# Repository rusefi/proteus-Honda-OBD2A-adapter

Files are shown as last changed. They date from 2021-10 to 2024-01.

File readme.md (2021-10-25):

https://github.com/rusefi/rusefi and https://github.com/mck1117/proteus

https://github.com/rusefi/rusefi/wiki/Vault-Of-Honda-OEM#obd-2

https://github.com/rusefi/rusefi/wiki/Honda-Civic-1996

[Connector spreadsheet](https://docs.google.com/spreadsheets/d/1NOu2Atvwz7war0sTAcp2MZZhsYdLY6VmwkuC-S1-yEU)

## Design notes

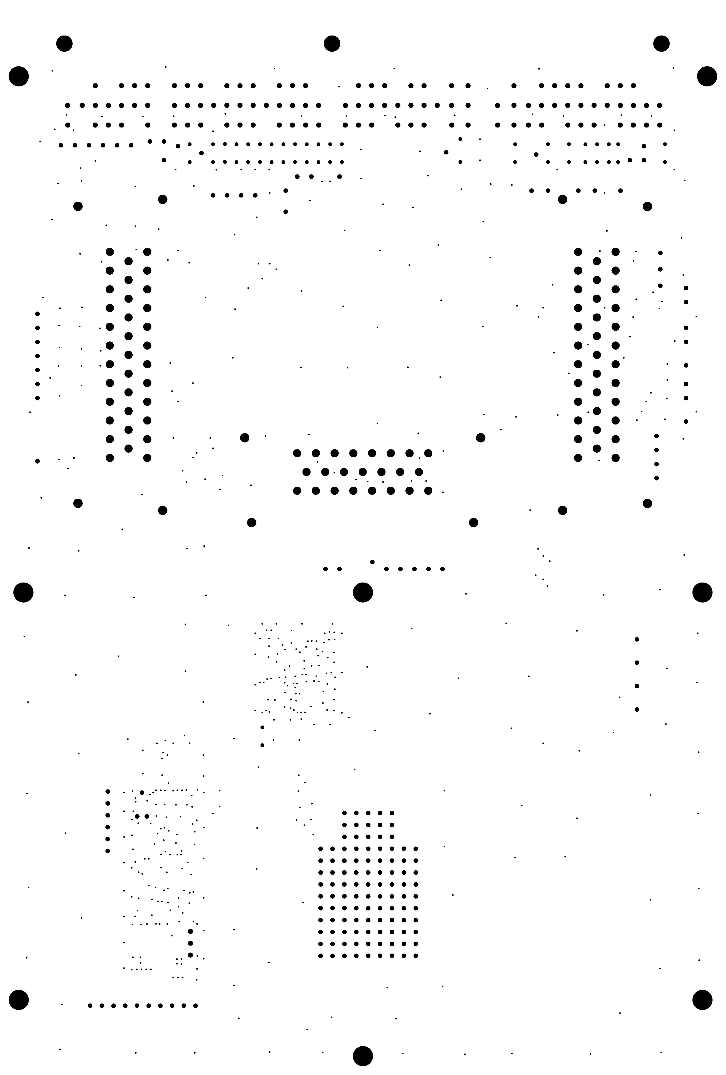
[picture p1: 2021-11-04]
boards/proteusOBD2Ahonda-a/boards/proteusOBD2Ahonda-a/board/misc/proteusOBD2Ahonda-a-outline.png

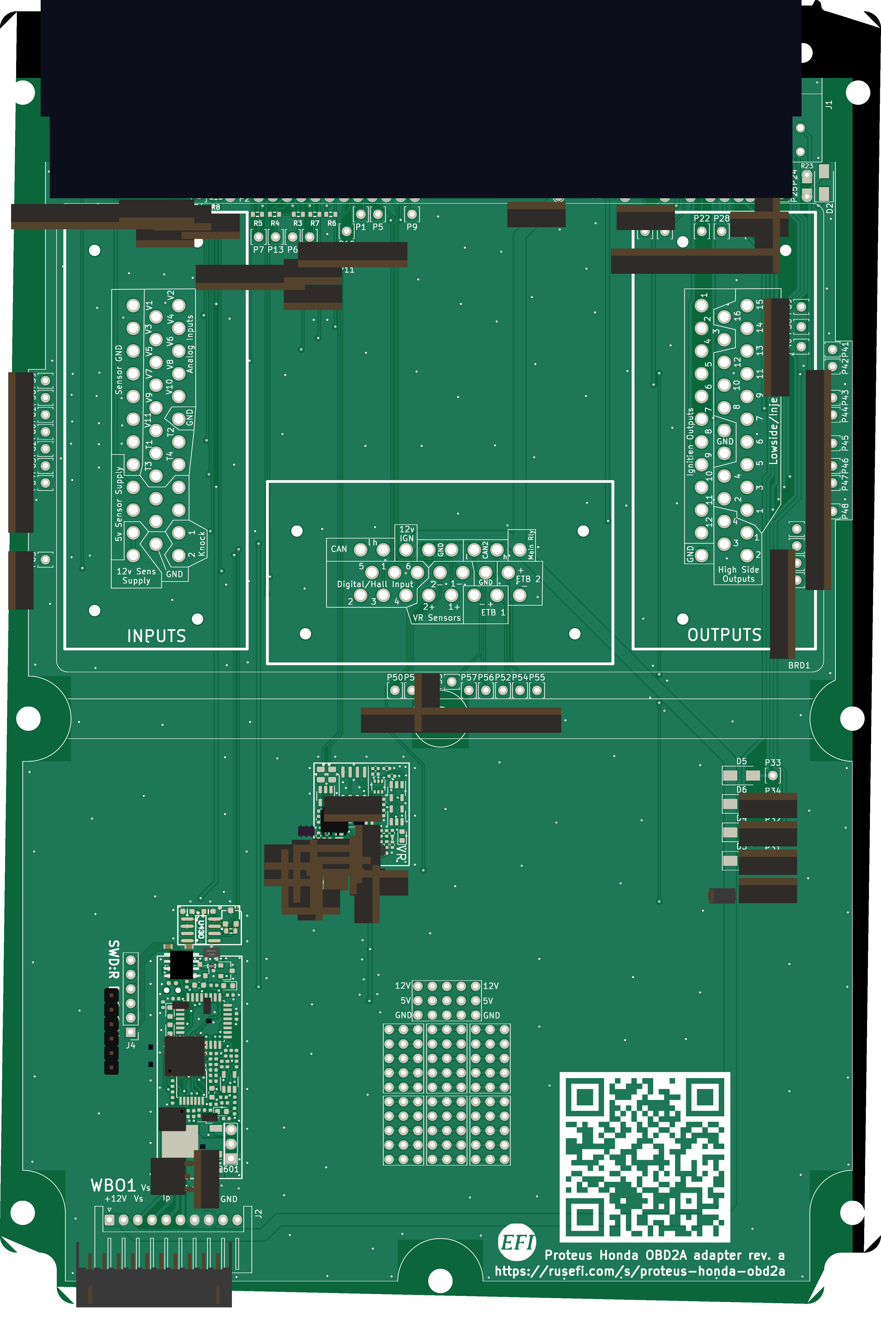
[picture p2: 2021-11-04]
boards/proteusOBD2Ahonda-a/boards/proteusOBD2Ahonda-a/board/proteusOBD2Ahonda-a.png

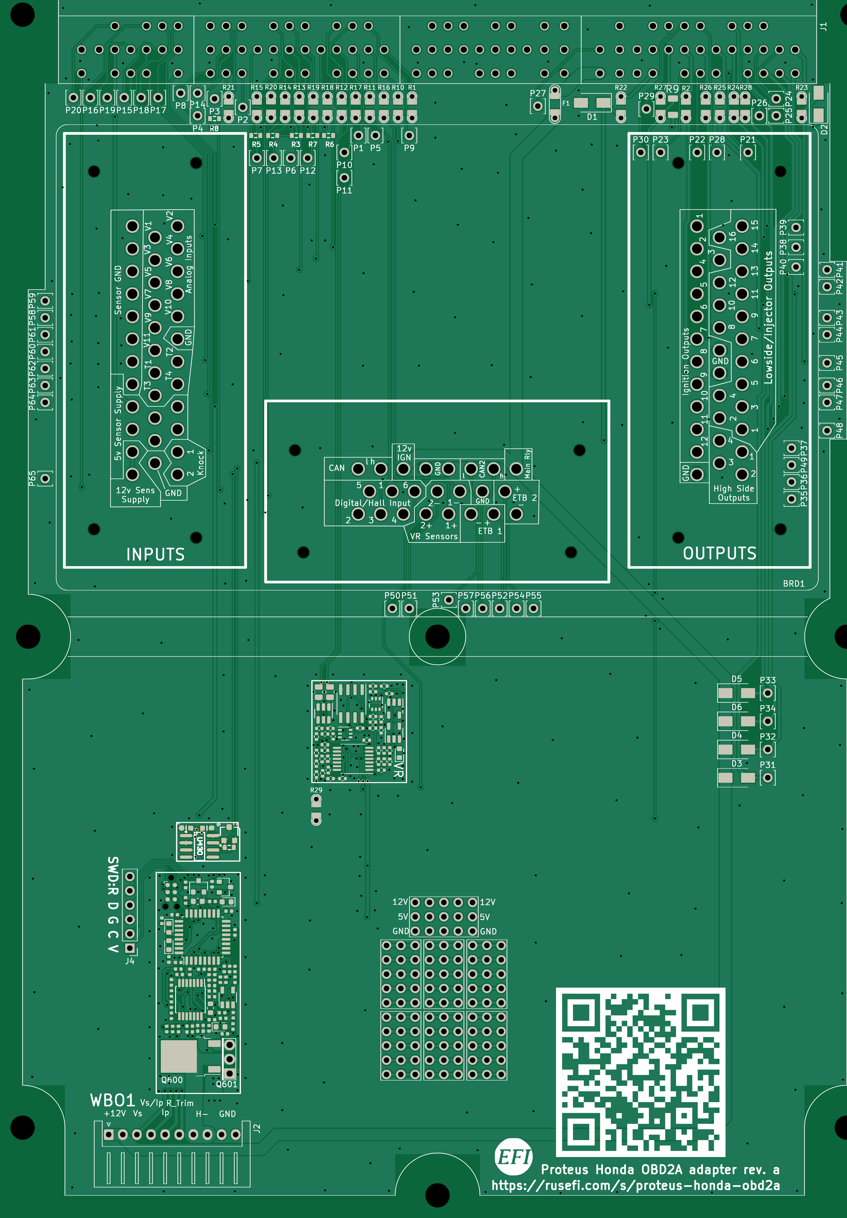
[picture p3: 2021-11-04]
boards/proteusOBD2Ahonda-a/boards/proteusOBD2Ahonda-a/board/misc/proteusOBD2Ahonda-a-top.png

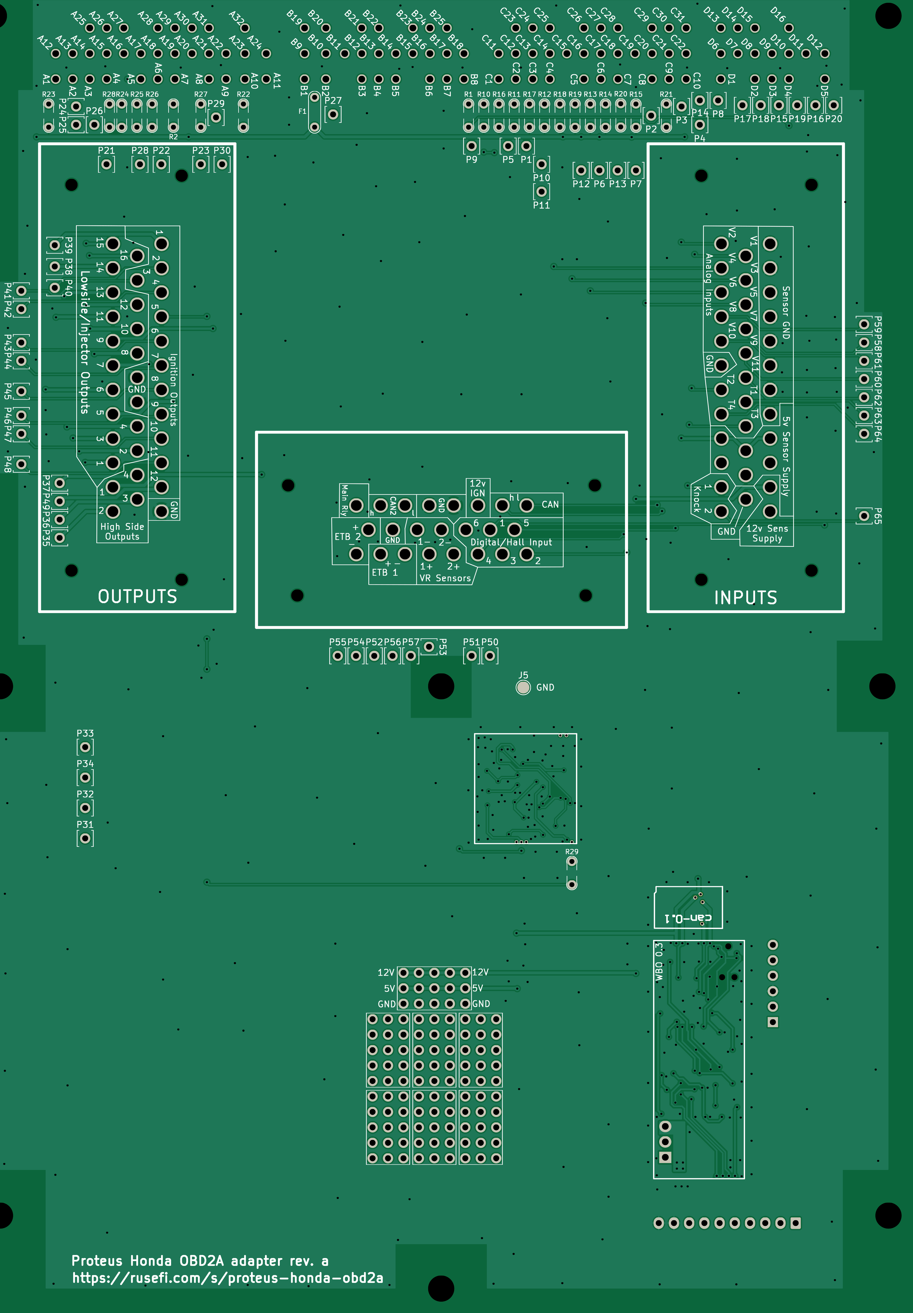
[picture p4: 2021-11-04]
boards/proteusOBD2Ahonda-a/boards/proteusOBD2Ahonda-a/board/misc/proteusOBD2Ahonda-a-bottom.png

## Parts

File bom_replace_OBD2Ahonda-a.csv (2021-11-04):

#WBO low-side (D2PAK | TO220)
Q600
Q601
#WBO STM32
U602

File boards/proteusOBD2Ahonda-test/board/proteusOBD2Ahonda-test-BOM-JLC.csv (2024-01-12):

Comment | Designator | Footprint | LCSC Part #
SS34 | D1, D2, D3, D4, D5, D6 | D_SMA | C8678
Fuse-Pad-Pad | F1 | PAD-1206-PAD | C182446
XH-10AW | J2 | JST_XH_S10B-XH-A_1x10_P2.50mm_Horizontal | C14652
Jumper-Pad-Pad | R1, R2, R10, R11, R12, R13, R14, R15, R16, R17, R18, R19, R20, R21, R22, R23, R24, R25, R26, R27, R28, R29 | PAD-0805-PAD | C17477
4.7k | R3, R4, R5, R6, R7, R8 | R0603 | C23162
1k | R9 | R1206 | C4410
1n | C751 | C0402 | C1523
470n | C752 | C0402 | C47339
100n | C753, C754, C759, C601, C602, C605, C608, C612, C613, C614, C615 | C0402 | C1525
1u | C755, C758, C761, C762, C763, C765, C766, C767, C600, C607, C609, C610, C611 | C0402 | C52923
10n | C756, C757, C760, C764 | C0402 | C15195
LED-GREEN-0603 | D751, D601 | LED-0603 | C72043
2.2k | R751 | R0402 | C25879
10k | R752, R753 | R0805 | C17414
12k | R754 | R0402 | C25752
100k | R755, R756, R758, R759, R615, R621 | R0402 | C25741
10k | R757, R762, R763, R767, R768, R604, R605, R613, R614, R618, R619, R625 | R0402 | C25744
68k | R760, R602, R603 | R0402 | C36871
10 | R761, R764, R769, R606 | R0402 | C25077
1k | R765, R766, R600, R601, R616, R617, R622, R626, R627, R628 | R0402 | C11702
SRV05-4-P-T7 | U751 | SOT23-6 | C85364
74AHC1G02 | U752, U757 | SOT23-5 | C7463
MCP6004 | U753, U600 | TSSOP14 | C50282
MAX9142 | U754 | SO8 | C18567
NC7SB3157P6X | U755, U756 | SOT-363 | C87403
33n | C603 | C0402 | C1585
4.7u | C616 | C0603 | C19666
LED-RED-0603 | D600, D603 | LED-0603 | C2286
LED-BLUE-0603 | D602 | LED-0603 | C72041
22k | R607 | R0402 | C25768
47 | R608 | R0402 | C25118
61.9 | R609 | R0603 | C23092
20k | R610, R611, R612 | R0402 | C25765
27k | R620, R623 | R0402 | C25771
3.3k | R624 | R0402 | C25890
AD8628 | U601 | TSOT23-5 | C29309
REF3033 | U603 | SOT-23 | C36658
XC6206P332MR | U604 | SOT-23 | C5446
100n | C430, C431 | C0603 | C14663
PESD1CAN | D430 | SOT-23 | C343993
120 | R430 | R0603 | C22787
TJA1051T/3/1J | U430 | SO8 | C38695

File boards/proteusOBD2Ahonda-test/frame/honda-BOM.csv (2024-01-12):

Comment | Designator | Footprint | LCSC Part #
proteus | BRD1 | proteus
SS34 | D1 | D_SMA | C8678
SS34 | D2 | D_SMA | C8678
SS34 | D3 | D_SMA | C8678
SS34 | D4 | D_SMA | C8678
SS34 | D5 | D_SMA | C8678
SS34 | D6 | D_SMA | C8678
Fuse-Pad-Pad | F1 | PAD-1206-PAD | C182446
RUSEFI_LOGO | G1 | rusefi_logo
PROTO_AREA | G2 | PROTO_AREA
PROTO_AREA | G3 | PROTO_AREA
PROTO_AREA | G4 | PROTO_AREA
PROTO_AREA | G5 | PROTO_AREA
PROTO_AREA | G6 | PROTO_AREA
PROTO_AREA | G7 | PROTO_AREA
PROTO_AREA | G8 | PROTO_AREA
MountingHole | H1 | MountingHole_4.3mm_M4
MountingHole | H2 | MountingHole_4.3mm_M4
MountingHole | H3 | MountingHole_4.3mm_M4
MountingHole | H4 | MountingHole_4.3mm_M4
MountingHole | H5 | MountingHole_4.3mm_M4
MountingHole | H6 | MountingHole_4.3mm_M4
MountingHole | H7 | MountingHole_4.3mm_M4
MountingHole | H8 | MountingHole_4.3mm_M4
TE_179686-6_104pin_Connector | J1 | TE_179686-6_104pin_Connector
XH-10AW | J2 | JST_XH_S10B-XH-A_1x10_P2.50mm_Horizontal | C14652
XH-10A | J3 | JST_XH_B10B-XH-A_1x10_P2.50mm_Vertical
Conn_01x06 | J4 | PinHeader_1x06_P2.54mm_Vertical
Conn_01x01 | J5 | TestPoint_Pad_D2.0mm
Module:vr-discrete/0.1 | M1 | vr-discrete
Module:wbo/0.3 | M2 | wbo
Module:can/0.1 | M3 | can
Pad | P1 | PAD-TH
Pad | P2 | PAD-TH
Pad | P3 | PAD-TH
Pad | P4 | PAD-TH
Pad | P5 | PAD-TH
Pad | P6 | PAD-TH
Pad | P7 | PAD-TH
Pad | P8 | PAD-TH
Pad | P9 | PAD-TH
Pad | P10 | PAD-TH
Pad | P11 | PAD-TH
Pad | P12 | PAD-TH
Pad | P13 | PAD-TH
Pad | P14 | PAD-TH
Pad | P15 | PAD-TH
Pad | P16 | PAD-TH
Pad | P17 | PAD-TH
Pad | P18 | PAD-TH
Pad | P19 | PAD-TH
Pad | P20 | PAD-TH
Pad | P21 | PAD-TH
Pad | P22 | PAD-TH
Pad | P23 | PAD-TH
Pad | P24 | PAD-TH
Pad | P25 | PAD-TH
Pad | P26 | PAD-TH
Pad | P27 | PAD-TH
Pad | P28 | PAD-TH
Pad | P29 | PAD-TH
Pad | P30 | PAD-TH
Pad | P31 | PAD-TH
Pad | P32 | PAD-TH
Pad | P33 | PAD-TH
Pad | P34 | PAD-TH
Pad | P35 | PAD-TH
Pad | P36 | PAD-TH
Pad | P37 | PAD-TH
Pad | P38 | PAD-TH
Pad | P39 | PAD-TH
Pad | P40 | PAD-TH
Pad | P41 | PAD-TH
Pad | P42 | PAD-TH
Pad | P43 | PAD-TH
Pad | P44 | PAD-TH
Pad | P45 | PAD-TH
Pad | P46 | PAD-TH
Pad | P47 | PAD-TH
Pad | P48 | PAD-TH
Pad | P49 | PAD-TH
Pad | P50 | PAD-TH
Pad | P51 | PAD-TH
Pad | P52 | PAD-TH
Pad | P53 | PAD-TH
Pad | P54 | PAD-TH
Pad | P55 | PAD-TH
Pad | P56 | PAD-TH
Pad | P57 | PAD-TH
Pad | P58 | PAD-TH
Pad | P59 | PAD-TH
Pad | P60 | PAD-TH
Pad | P61 | PAD-TH
Pad | P62 | PAD-TH
Pad | P63 | PAD-TH
Pad | P64 | PAD-TH
Pad | P65 | PAD-TH
Jumper-Pad-Pad | R1 | PAD-0805-PAD | C17477
Jumper-Pad-Pad | R2 | PAD-0805-PAD | C17477
4.7k | R3 | R0603 | C23162
4.7k | R4 | R0603 | C23162
4.7k | R5 | R0603 | C23162
4.7k | R6 | R0603 | C23162
4.7k | R7 | R0603 | C23162
4.7k | R8 | R0603 | C23162
1k | R9 | R1206 | C4410
Jumper-Pad-Pad | R10 | PAD-0805-PAD | C17477
Jumper-Pad-Pad | R11 | PAD-0805-PAD | C17477
Jumper-Pad-Pad | R12 | PAD-0805-PAD | C17477
Jumper-Pad-Pad | R13 | PAD-0805-PAD | C17477
Jumper-Pad-Pad | R14 | PAD-0805-PAD | C17477
Jumper-Pad-Pad | R15 | PAD-0805-PAD | C17477
Jumper-Pad-Pad | R16 | PAD-0805-PAD | C17477
Jumper-Pad-Pad | R17 | PAD-0805-PAD | C17477
Jumper-Pad-Pad | R18 | PAD-0805-PAD | C17477
Jumper-Pad-Pad | R19 | PAD-0805-PAD | C17477
Jumper-Pad-Pad | R20 | PAD-0805-PAD | C17477
Jumper-Pad-Pad | R21 | PAD-0805-PAD | C17477
Jumper-Pad-Pad | R22 | PAD-0805-PAD | C17477
Jumper-Pad-Pad | R23 | PAD-0805-PAD | C17477
Jumper-Pad-Pad | R24 | PAD-0805-PAD | C17477
Jumper-Pad-Pad | R25 | PAD-0805-PAD | C17477
Jumper-Pad-Pad | R26 | PAD-0805-PAD | C17477
Jumper-Pad-Pad | R27 | PAD-0805-PAD | C17477
Jumper-Pad-Pad | R28 | PAD-0805-PAD | C17477
Jumper-Pad-Pad | R29 | PAD-0805-PAD | C17477

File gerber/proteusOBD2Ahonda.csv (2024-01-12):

Comment | Designator | Footprint | LCSC Part #
proteus | BRD1 | kicad6-libraries:proteus
SS34 | D1 | Diode_SMD:D_SMA | C8678
SS34 | D2 | Diode_SMD:D_SMA | C8678
SS34 | D3 | Diode_SMD:D_SMA | C8678
SS34 | D4 | Diode_SMD:D_SMA | C8678
SS34 | D5 | Diode_SMD:D_SMA | C8678
SS34 | D6 | Diode_SMD:D_SMA | C8678
Fuse-Pad-Pad | F1 | hellen-one-common:PAD-1206-PAD | C182446
RUSEFI_LOGO | G1 | kicad6-libraries:rusefi_logo
PROTO_AREA | G2 | hellen-one-common:PROTO_AREA
PROTO_AREA | G3 | hellen-one-common:PROTO_AREA
PROTO_AREA | G4 | hellen-one-common:PROTO_AREA
PROTO_AREA | G5 | hellen-one-common:PROTO_AREA
PROTO_AREA | G6 | hellen-one-common:PROTO_AREA
PROTO_AREA | G7 | hellen-one-common:PROTO_AREA
PROTO_AREA | G8 | hellen-one-common:PROTO_AREA
MountingHole | H1 | MountingHole:MountingHole_4.3mm_M4
MountingHole | H2 | MountingHole:MountingHole_4.3mm_M4
MountingHole | H3 | MountingHole:MountingHole_4.3mm_M4
MountingHole | H4 | MountingHole:MountingHole_4.3mm_M4
MountingHole | H5 | MountingHole:MountingHole_4.3mm_M4
MountingHole | H6 | MountingHole:MountingHole_4.3mm_M4
MountingHole | H7 | MountingHole:MountingHole_4.3mm_M4
MountingHole | H8 | MountingHole:MountingHole_4.3mm_M4
TE_179686-6_104pin_Connector | J1 | kicad6-libraries:TE_179686-6_104pin_Connector
XH-10AW | J2 | Connector_JST:JST_XH_S10B-XH-A_1x10_P2.50mm_Horizontal | C14652
XH-10A | J3 | Connector_JST:JST_XH_B10B-XH-A_1x10_P2.50mm_Vertical
Conn_01x06 | J4 | Connector_PinHeader_2.54mm:PinHeader_1x06_P2.54mm_Vertical
Conn_01x01 | J5 | TestPoint:TestPoint_Pad_D2.0mm
Module-vr-discrete-0.1 | M1 | hellen-one-vr-discrete-0.1:vr-discrete
Module-wbo-0.3 | M2 | hellen-one-wbo-0.3:wbo
Module-can-0.1 | M3 | hellen-one-can-0.1:can
Pad | P1 | hellen-one-common:PAD-TH
Pad | P2 | hellen-one-common:PAD-TH
Pad | P3 | hellen-one-common:PAD-TH
Pad | P4 | hellen-one-common:PAD-TH
Pad | P5 | hellen-one-common:PAD-TH
Pad | P6 | hellen-one-common:PAD-TH
Pad | P7 | hellen-one-common:PAD-TH
Pad | P8 | hellen-one-common:PAD-TH
Pad | P9 | hellen-one-common:PAD-TH
Pad | P10 | hellen-one-common:PAD-TH
Pad | P11 | hellen-one-common:PAD-TH
Pad | P12 | hellen-one-common:PAD-TH
Pad | P13 | hellen-one-common:PAD-TH
Pad | P14 | hellen-one-common:PAD-TH
Pad | P15 | hellen-one-common:PAD-TH
Pad | P16 | hellen-one-common:PAD-TH
Pad | P17 | hellen-one-common:PAD-TH
Pad | P18 | hellen-one-common:PAD-TH
Pad | P19 | hellen-one-common:PAD-TH
Pad | P20 | hellen-one-common:PAD-TH
Pad | P21 | hellen-one-common:PAD-TH
Pad | P22 | hellen-one-common:PAD-TH
Pad | P23 | hellen-one-common:PAD-TH
Pad | P24 | hellen-one-common:PAD-TH
Pad | P25 | hellen-one-common:PAD-TH
Pad | P26 | hellen-one-common:PAD-TH
Pad | P27 | hellen-one-common:PAD-TH
Pad | P28 | hellen-one-common:PAD-TH
Pad | P29 | hellen-one-common:PAD-TH
Pad | P30 | hellen-one-common:PAD-TH
Pad | P31 | hellen-one-common:PAD-TH
Pad | P32 | hellen-one-common:PAD-TH
Pad | P33 | hellen-one-common:PAD-TH
Pad | P34 | hellen-one-common:PAD-TH
Pad | P35 | hellen-one-common:PAD-TH
Pad | P36 | hellen-one-common:PAD-TH
Pad | P37 | hellen-one-common:PAD-TH
Pad | P38 | hellen-one-common:PAD-TH
Pad | P39 | hellen-one-common:PAD-TH
Pad | P40 | hellen-one-common:PAD-TH
Pad | P41 | hellen-one-common:PAD-TH
Pad | P42 | hellen-one-common:PAD-TH
Pad | P43 | hellen-one-common:PAD-TH
Pad | P44 | hellen-one-common:PAD-TH
Pad | P45 | hellen-one-common:PAD-TH
Pad | P46 | hellen-one-common:PAD-TH
Pad | P47 | hellen-one-common:PAD-TH
Pad | P48 | hellen-one-common:PAD-TH
Pad | P49 | hellen-one-common:PAD-TH
Pad | P50 | hellen-one-common:PAD-TH
Pad | P51 | hellen-one-common:PAD-TH
Pad | P52 | hellen-one-common:PAD-TH
Pad | P53 | hellen-one-common:PAD-TH
Pad | P54 | hellen-one-common:PAD-TH
Pad | P55 | hellen-one-common:PAD-TH
Pad | P56 | hellen-one-common:PAD-TH
Pad | P57 | hellen-one-common:PAD-TH
Pad | P58 | hellen-one-common:PAD-TH
Pad | P59 | hellen-one-common:PAD-TH
Pad | P60 | hellen-one-common:PAD-TH
Pad | P61 | hellen-one-common:PAD-TH
Pad | P62 | hellen-one-common:PAD-TH
Pad | P63 | hellen-one-common:PAD-TH
Pad | P64 | hellen-one-common:PAD-TH
Pad | P65 | hellen-one-common:PAD-TH
Jumper-Pad-Pad | R1 | hellen-one-common:PAD-0805-PAD | C17477
Jumper-Pad-Pad | R2 | hellen-one-common:PAD-0805-PAD | C17477
4.7k | R3 | hellen-one-common:R0603 | C23162
4.7k | R4 | hellen-one-common:R0603 | C23162
4.7k | R5 | hellen-one-common:R0603 | C23162
4.7k | R6 | hellen-one-common:R0603 | C23162
4.7k | R7 | hellen-one-common:R0603 | C23162
4.7k | R8 | hellen-one-common:R0603 | C23162
1k | R9 | hellen-one-common:R1206 | C4410
Jumper-Pad-Pad | R10 | hellen-one-common:PAD-0805-PAD | C17477
Jumper-Pad-Pad | R11 | hellen-one-common:PAD-0805-PAD | C17477
Jumper-Pad-Pad | R12 | hellen-one-common:PAD-0805-PAD | C17477
Jumper-Pad-Pad | R13 | hellen-one-common:PAD-0805-PAD | C17477
Jumper-Pad-Pad | R14 | hellen-one-common:PAD-0805-PAD | C17477
Jumper-Pad-Pad | R15 | hellen-one-common:PAD-0805-PAD | C17477
Jumper-Pad-Pad | R16 | hellen-one-common:PAD-0805-PAD | C17477
Jumper-Pad-Pad | R17 | hellen-one-common:PAD-0805-PAD | C17477
Jumper-Pad-Pad | R18 | hellen-one-common:PAD-0805-PAD | C17477
Jumper-Pad-Pad | R19 | hellen-one-common:PAD-0805-PAD | C17477
Jumper-Pad-Pad | R20 | hellen-one-common:PAD-0805-PAD | C17477
Jumper-Pad-Pad | R21 | hellen-one-common:PAD-0805-PAD | C17477
Jumper-Pad-Pad | R22 | hellen-one-common:PAD-0805-PAD | C17477
Jumper-Pad-Pad | R23 | hellen-one-common:PAD-0805-PAD | C17477
Jumper-Pad-Pad | R24 | hellen-one-common:PAD-0805-PAD | C17477
Jumper-Pad-Pad | R25 | hellen-one-common:PAD-0805-PAD | C17477
Jumper-Pad-Pad | R26 | hellen-one-common:PAD-0805-PAD | C17477
Jumper-Pad-Pad | R27 | hellen-one-common:PAD-0805-PAD | C17477
Jumper-Pad-Pad | R28 | hellen-one-common:PAD-0805-PAD | C17477
Jumper-Pad-Pad | R29 | hellen-one-common:PAD-0805-PAD | C17477

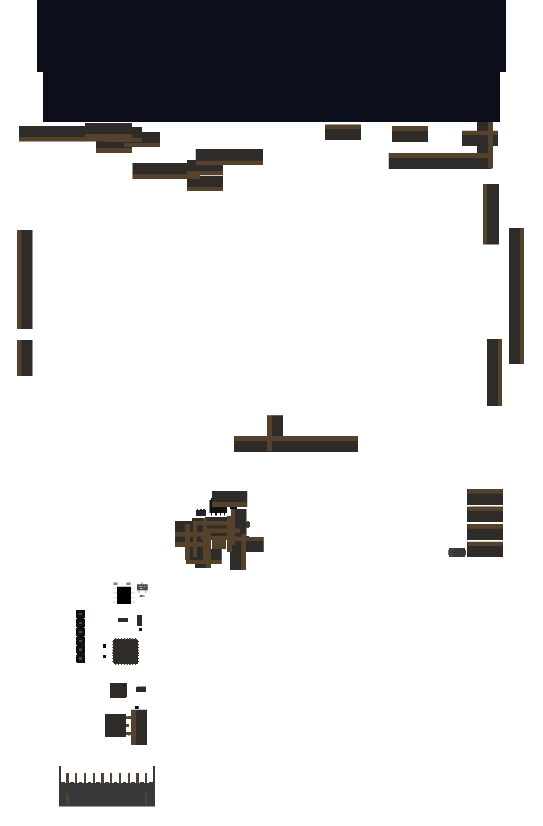
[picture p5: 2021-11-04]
boards/proteusOBD2Ahonda-a/boards/proteusOBD2Ahonda-a/board/misc/proteusOBD2Ahonda-a-components.png

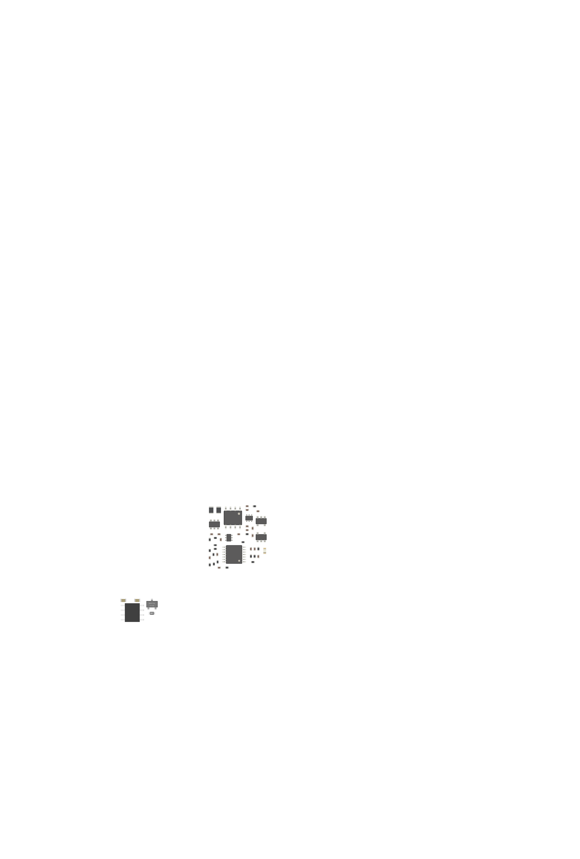
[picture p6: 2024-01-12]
boards/proteusOBD2Ahonda-test/board/misc/proteusOBD2Ahonda-test-components.png

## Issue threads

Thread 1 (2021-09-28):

Data readiness

rusefillc, 2021-09-28:
https://www.ek9.org/index.php?threads/honda-usefull-ecu-pinouts-obd2b-obd2a-obd1.201/

rusefillc, 2021-09-28:
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

rusefillc, 2021-09-29:
connector footprint pushed into repo, please init schematics files

Qwerty-OFF, 2021-10-01:
Done

rusefillc, 2021-10-01:
@Timbelom now it's your turn :)

rusefillc, 2021-10-03:
@Timbelom maybe simpler to use https://github.com/rusefi/rusefi/wiki/Honda-Civic-1996

rusefillc, 2021-10-12:
@Timbelom not available

@Qwerty-OFF please proceed with data entry

Closed 2021-11-04.

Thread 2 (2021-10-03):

case outline

rusefillc, 2021-10-03:
that middle of the case reinforcement bar is in our way we will be cutting it out

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

Closed 2021-11-04.

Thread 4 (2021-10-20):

trigger signals

rusefillc, 2021-10-20:
Wiring harness has 4 sensors. We would use two

TDC simple - we never use it
CYP would require vr-descrete module, that one is impossible to handle by MAX992x on Proteus due to MAX992x 85ms watchdog
CKP should be wired into Proteus by default. We also need jumpers allowing to wire crankshaft speed fluctuation.

Open Q if we simply wire crankshaft speed fluctuation to Proteus second VR?

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

Qwerty-OFF, 2021-10-29:
@mck1117 why we need a voltage translator? I see that the threshold generator is powered by 5V. Will 5V use require unwanted changes to PWM settings?

mck1117, 2021-11-02:
Not the end of the world to make the change in software, but yes, that's why it would need to be different.  The hardware inside the VR module expects a 0-3.3v signal.  5v PWM wouldn't hurt it or anything, we'd just have to compensate in software.

Qwerty-OFF, 2021-11-04:
Connected to IGN5 through jumper

Closed 2021-11-04.

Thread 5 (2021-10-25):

Align pin usage with default pinout

rusefillc, 2021-10-25:
injector 1 please use LS1

See
three YAML files at https://github.com/rusefi/rusefi/tree/master/firmware/config/boards/proteus/connectors

see https://rusefi.com/docs/pinouts/proteus/ online tool

Qwerty-OFF, 2021-11-04:
Please close if ok

Closed 2021-11-04.

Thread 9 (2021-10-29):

inverted pins as comment on symbol

rusefillc, 2021-10-29:
please add "inv 12" for "A1"
"INV 1" for A12

smaller font or less black grey or something to indicate secondary natute

Qwerty-OFF, 2021-10-30:
A12 or A24 should be "inv 1"? If we want to use right angle connectors sometimes, it is necessary to place pin 1 of this connector in position A24.

rusefillc, 2021-10-30:
let's forget about right angle connector for now. A12 would be "inv 1" that's the way current plastic 35 pin flips, right?

Qwerty-OFF, 2021-10-30:
Can now be installed in two positions.  Make it install in only one way?

rusefillc, 2021-10-30:
Absolutely please limit because i made mistake already. Only latches out

Qwerty-OFF, 2021-10-30:
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

Qwerty-OFF, 2021-11-04:
Please close if ok

Closed 2021-11-04.

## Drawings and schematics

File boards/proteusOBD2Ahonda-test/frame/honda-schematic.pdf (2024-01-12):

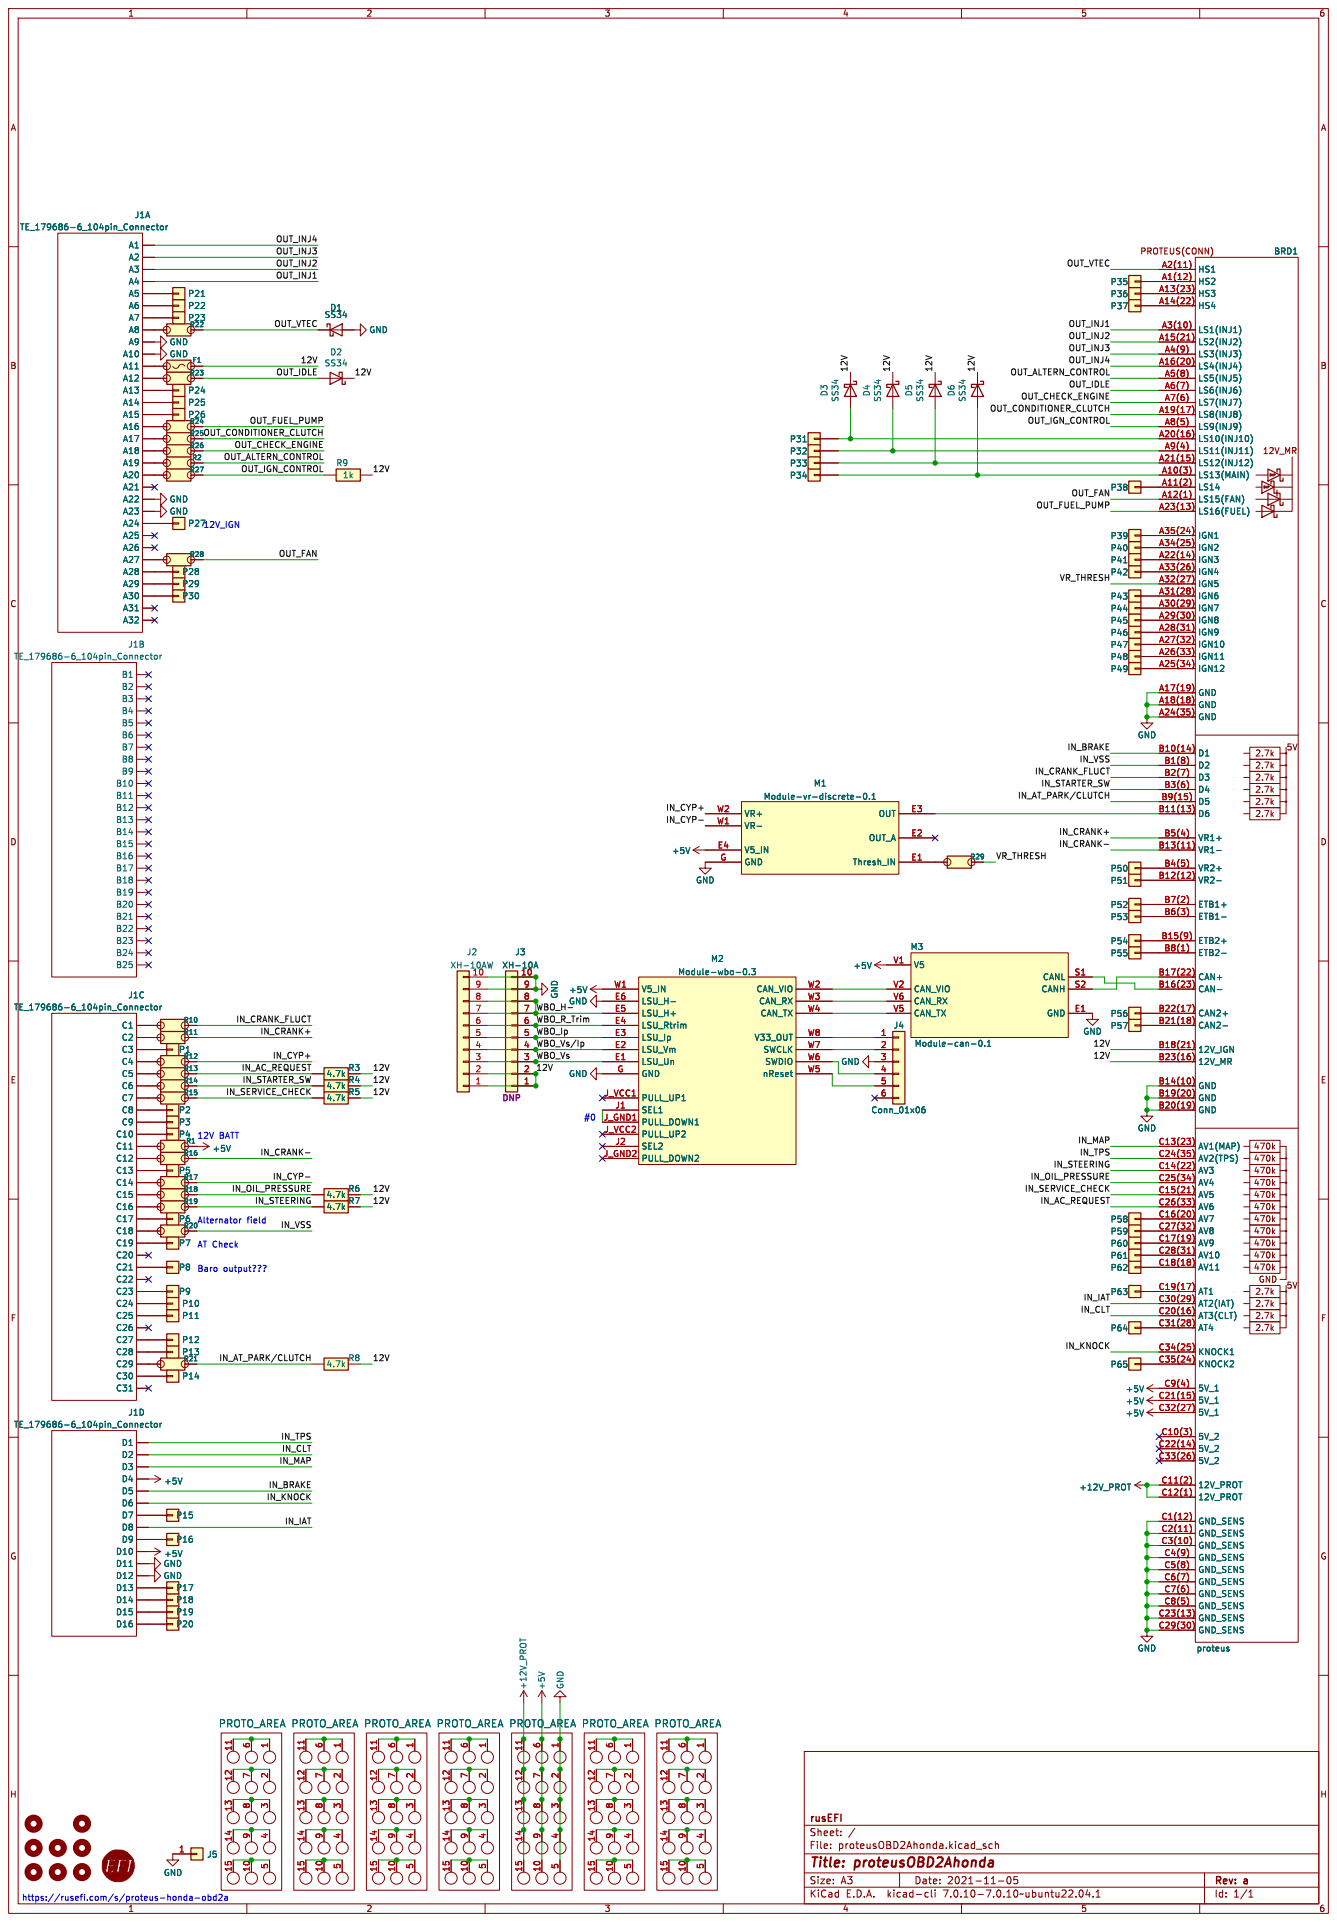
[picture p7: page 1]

GND E1 CANL S1 CANH S2 V5 V1 CAN_VIO V2 CAN_TX V5 CAN_RX V6 M3Module-can-0.1

File: proteusOBD2Ahonda.kicad_sch Sheet: / rusEFI GND

https://rusefi.com/s/proteus-honda-obd2a

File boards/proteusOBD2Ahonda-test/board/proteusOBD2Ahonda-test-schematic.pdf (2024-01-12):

# LS15(FAN) A12(1) HS3 A13(23) HS4 A14(22)

# LS4(INJ4) A16(20) GND A17(19) GND A18(18)


GND E1 CANL S1 CANH S2 V5 V1 CAN_VIO V2 CAN_TX V5 CAN_RX V6 M3Module-can-0.1

File: proteusOBD2Ahonda.kicad_sch Sheet: / rusEFI GND

https://rusefi.com/s/proteus-honda-obd2a

# +5V GND

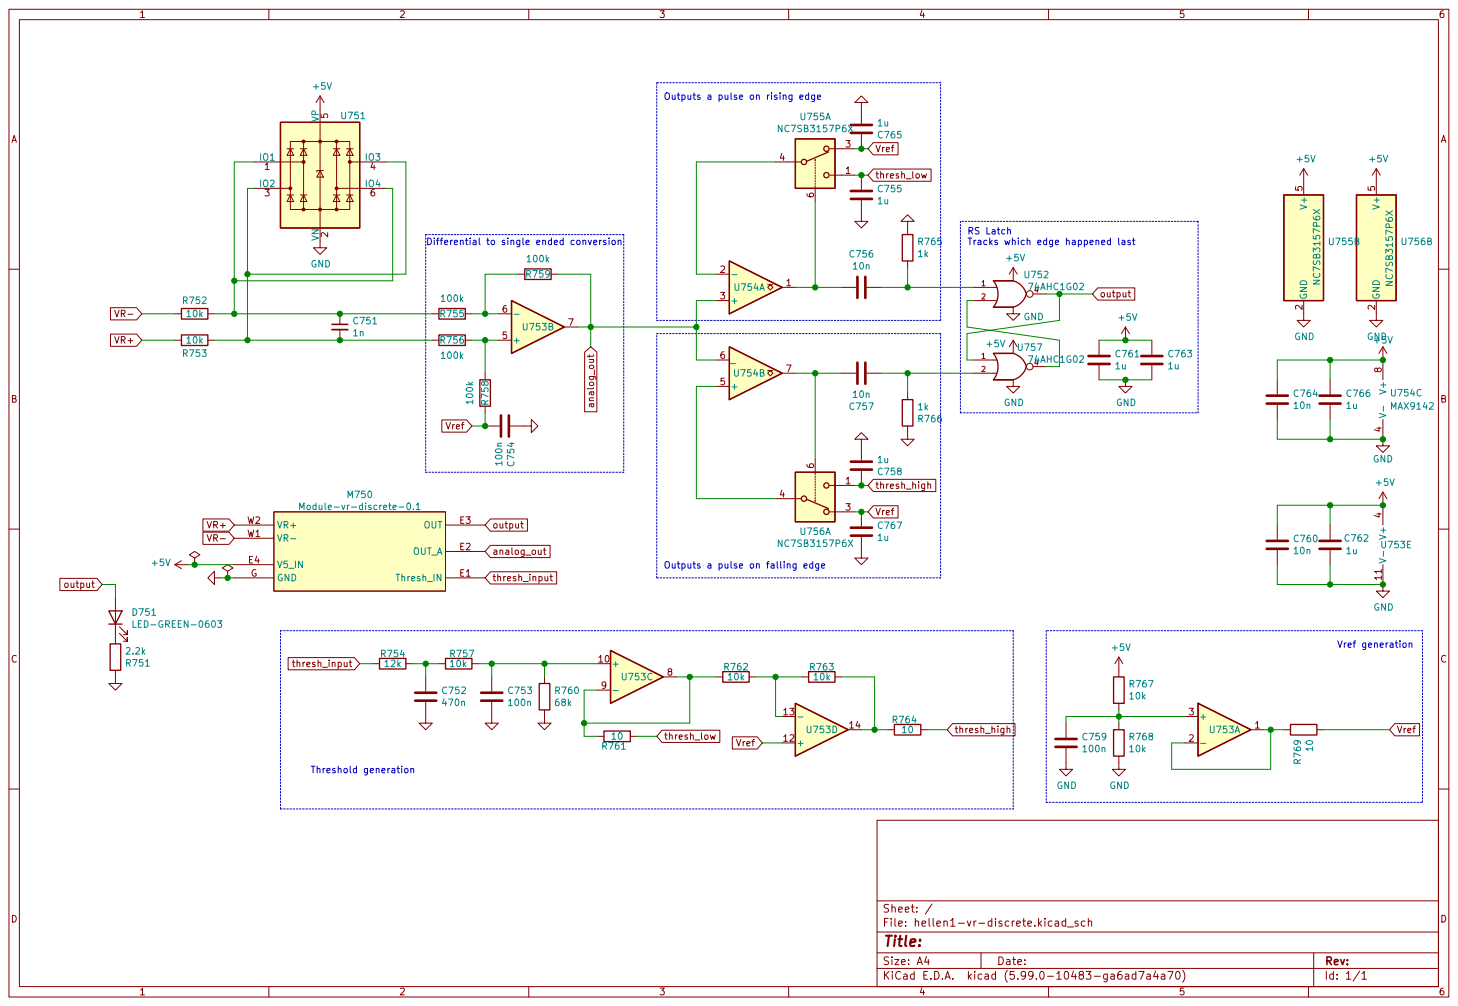
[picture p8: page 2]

Outputs a pulse on falling edge

1kR600

3.3k R623

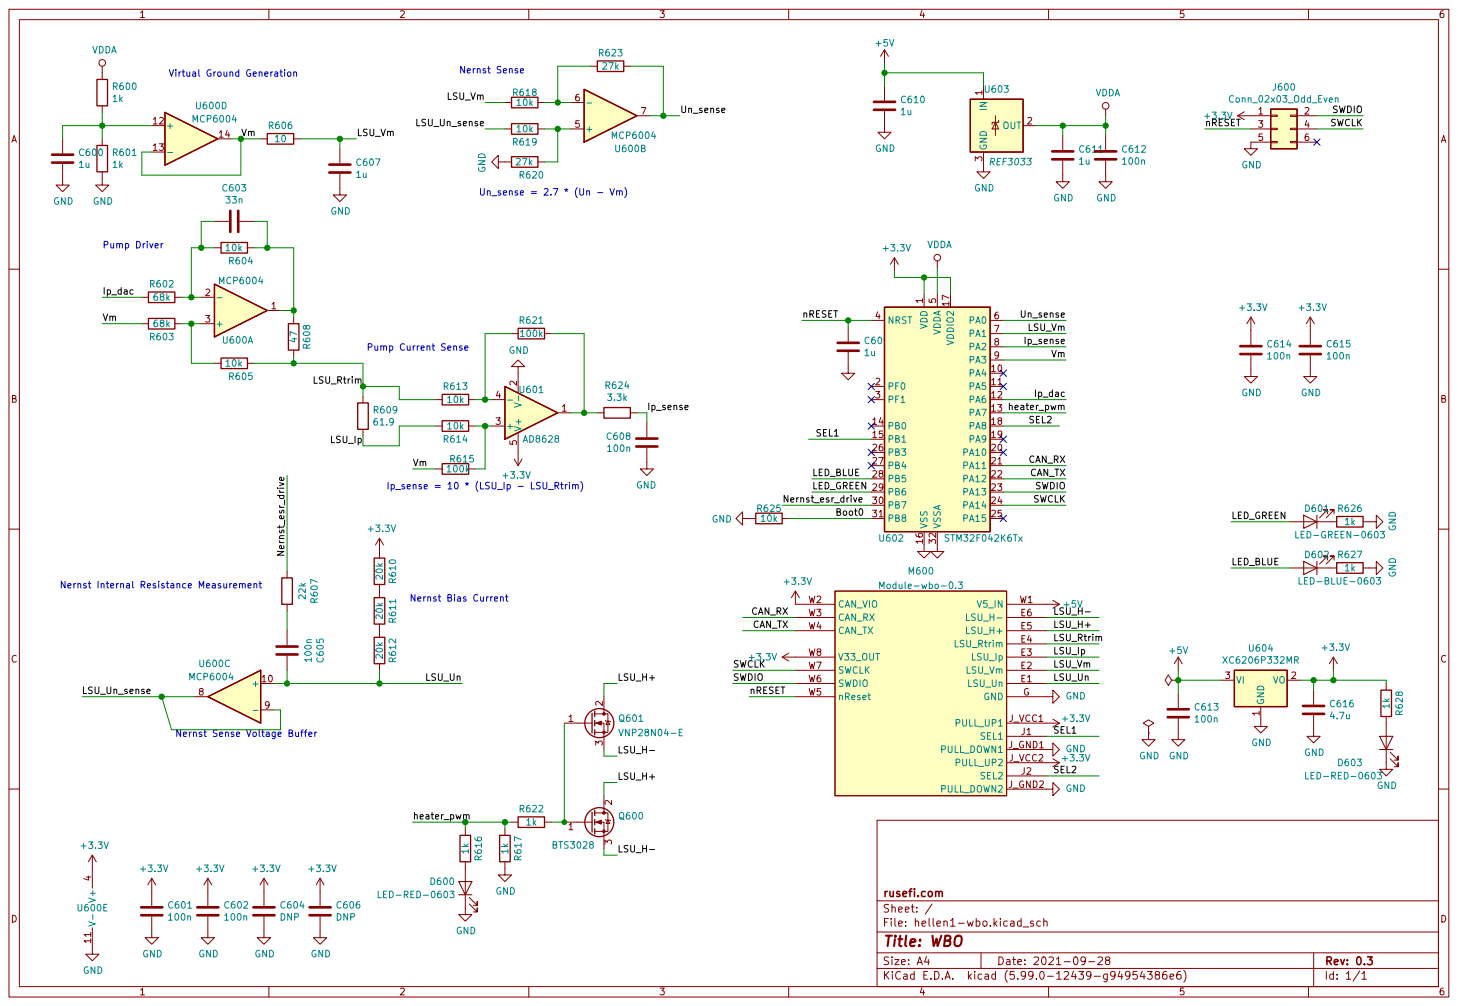
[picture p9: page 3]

Pump Current Sense Nernst Sense

LSU_Vm
Pump Driver Nernst Internal Resistance Measurement

1 VO 2 VI 3 U604 XC6206P332MR GND GND

1 PA4 10 PA5 11 PA6 12 PA7 13 PB0 14 PB1 15 VSS 16 VDDIO2 17 PA8 18 PA9 19 PF0 2 PA10 20 PA11 21 PA12 22 PA13 23 PA14 24 PA15 25 PB3 26 PB4 27 PB5 28 PB6 29 PF1 3 PB7 30 PB8 31 VSSA 32 NRST 4 VDDA

LED-RED-0603 ¹⁰⁰n C⁶⁰⁵ C604 DNP

Nernst Sense Voltage Buffer

1k GND GND R⁶¹⁶ ¹k

File: hellen1-wbo.kicad_sch Sheet: / rusefi.com

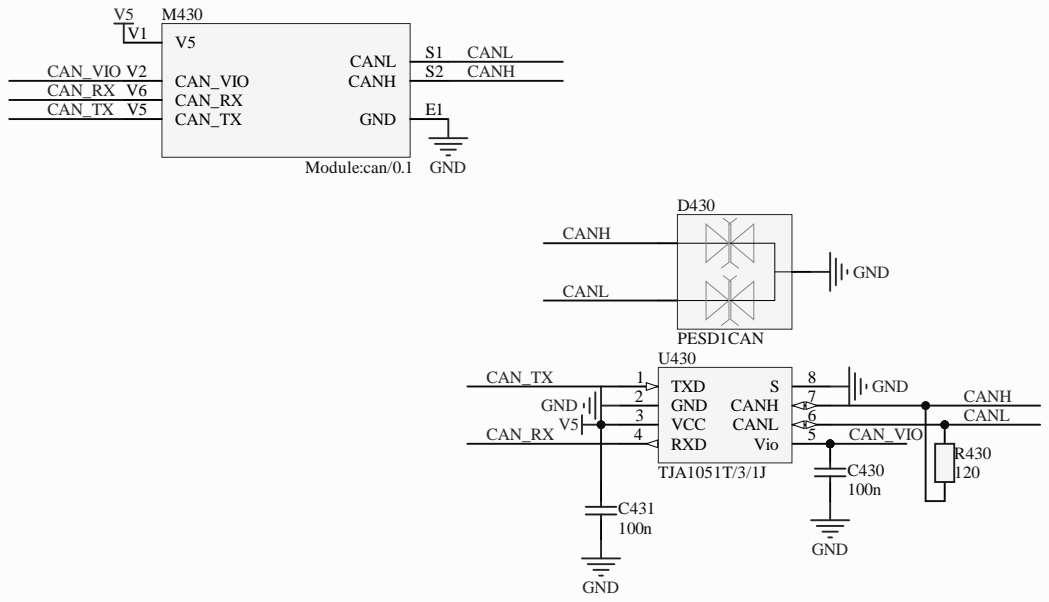
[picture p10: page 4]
andreika; Size:; Author:; Date:; Revision:; Sheet; PESD1CAN; GND; CANH; CANL; TXD 1 GND 2 VCC 3; Vio; 5 RXD 4; 6 CANH; TJA1051T/3/1J; CANH CANL; CAN_TX; CAN_RX; CAN_VIO; CAN_VIO V2; S2 CANL; CAN_TX V5; CAN_RX V6; Module:can/0.1

Hellen-One CAN
Title:

rusEFI EMS
Hellen-One Platform
https://rusefi.com/s/hellen72

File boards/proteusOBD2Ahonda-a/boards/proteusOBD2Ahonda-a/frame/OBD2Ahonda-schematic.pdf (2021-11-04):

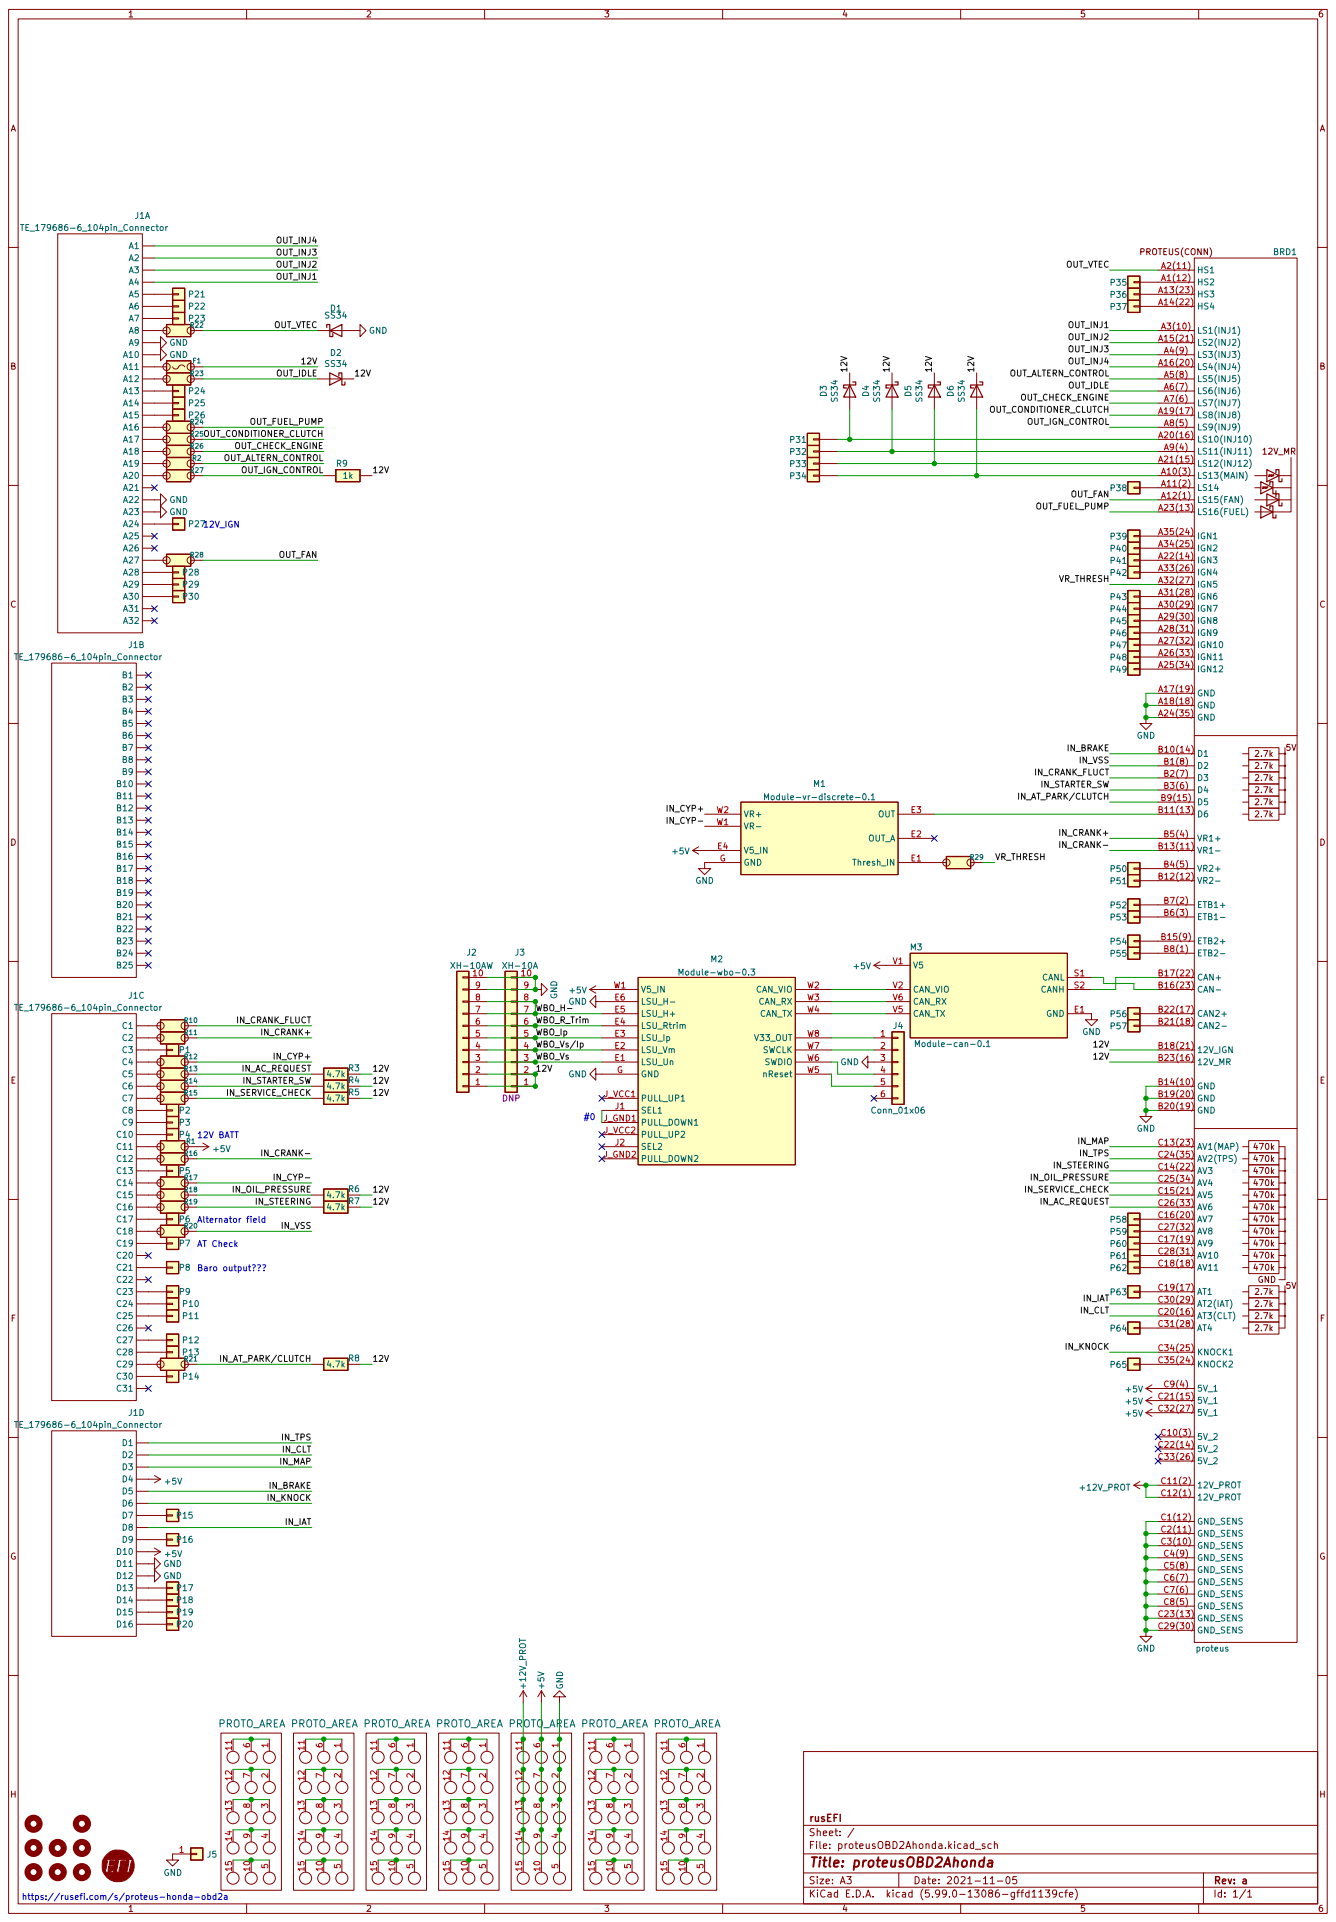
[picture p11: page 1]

8 | J3 XH-10A DNP 8

https://rusefi.com/s/proteus-honda-obd2a

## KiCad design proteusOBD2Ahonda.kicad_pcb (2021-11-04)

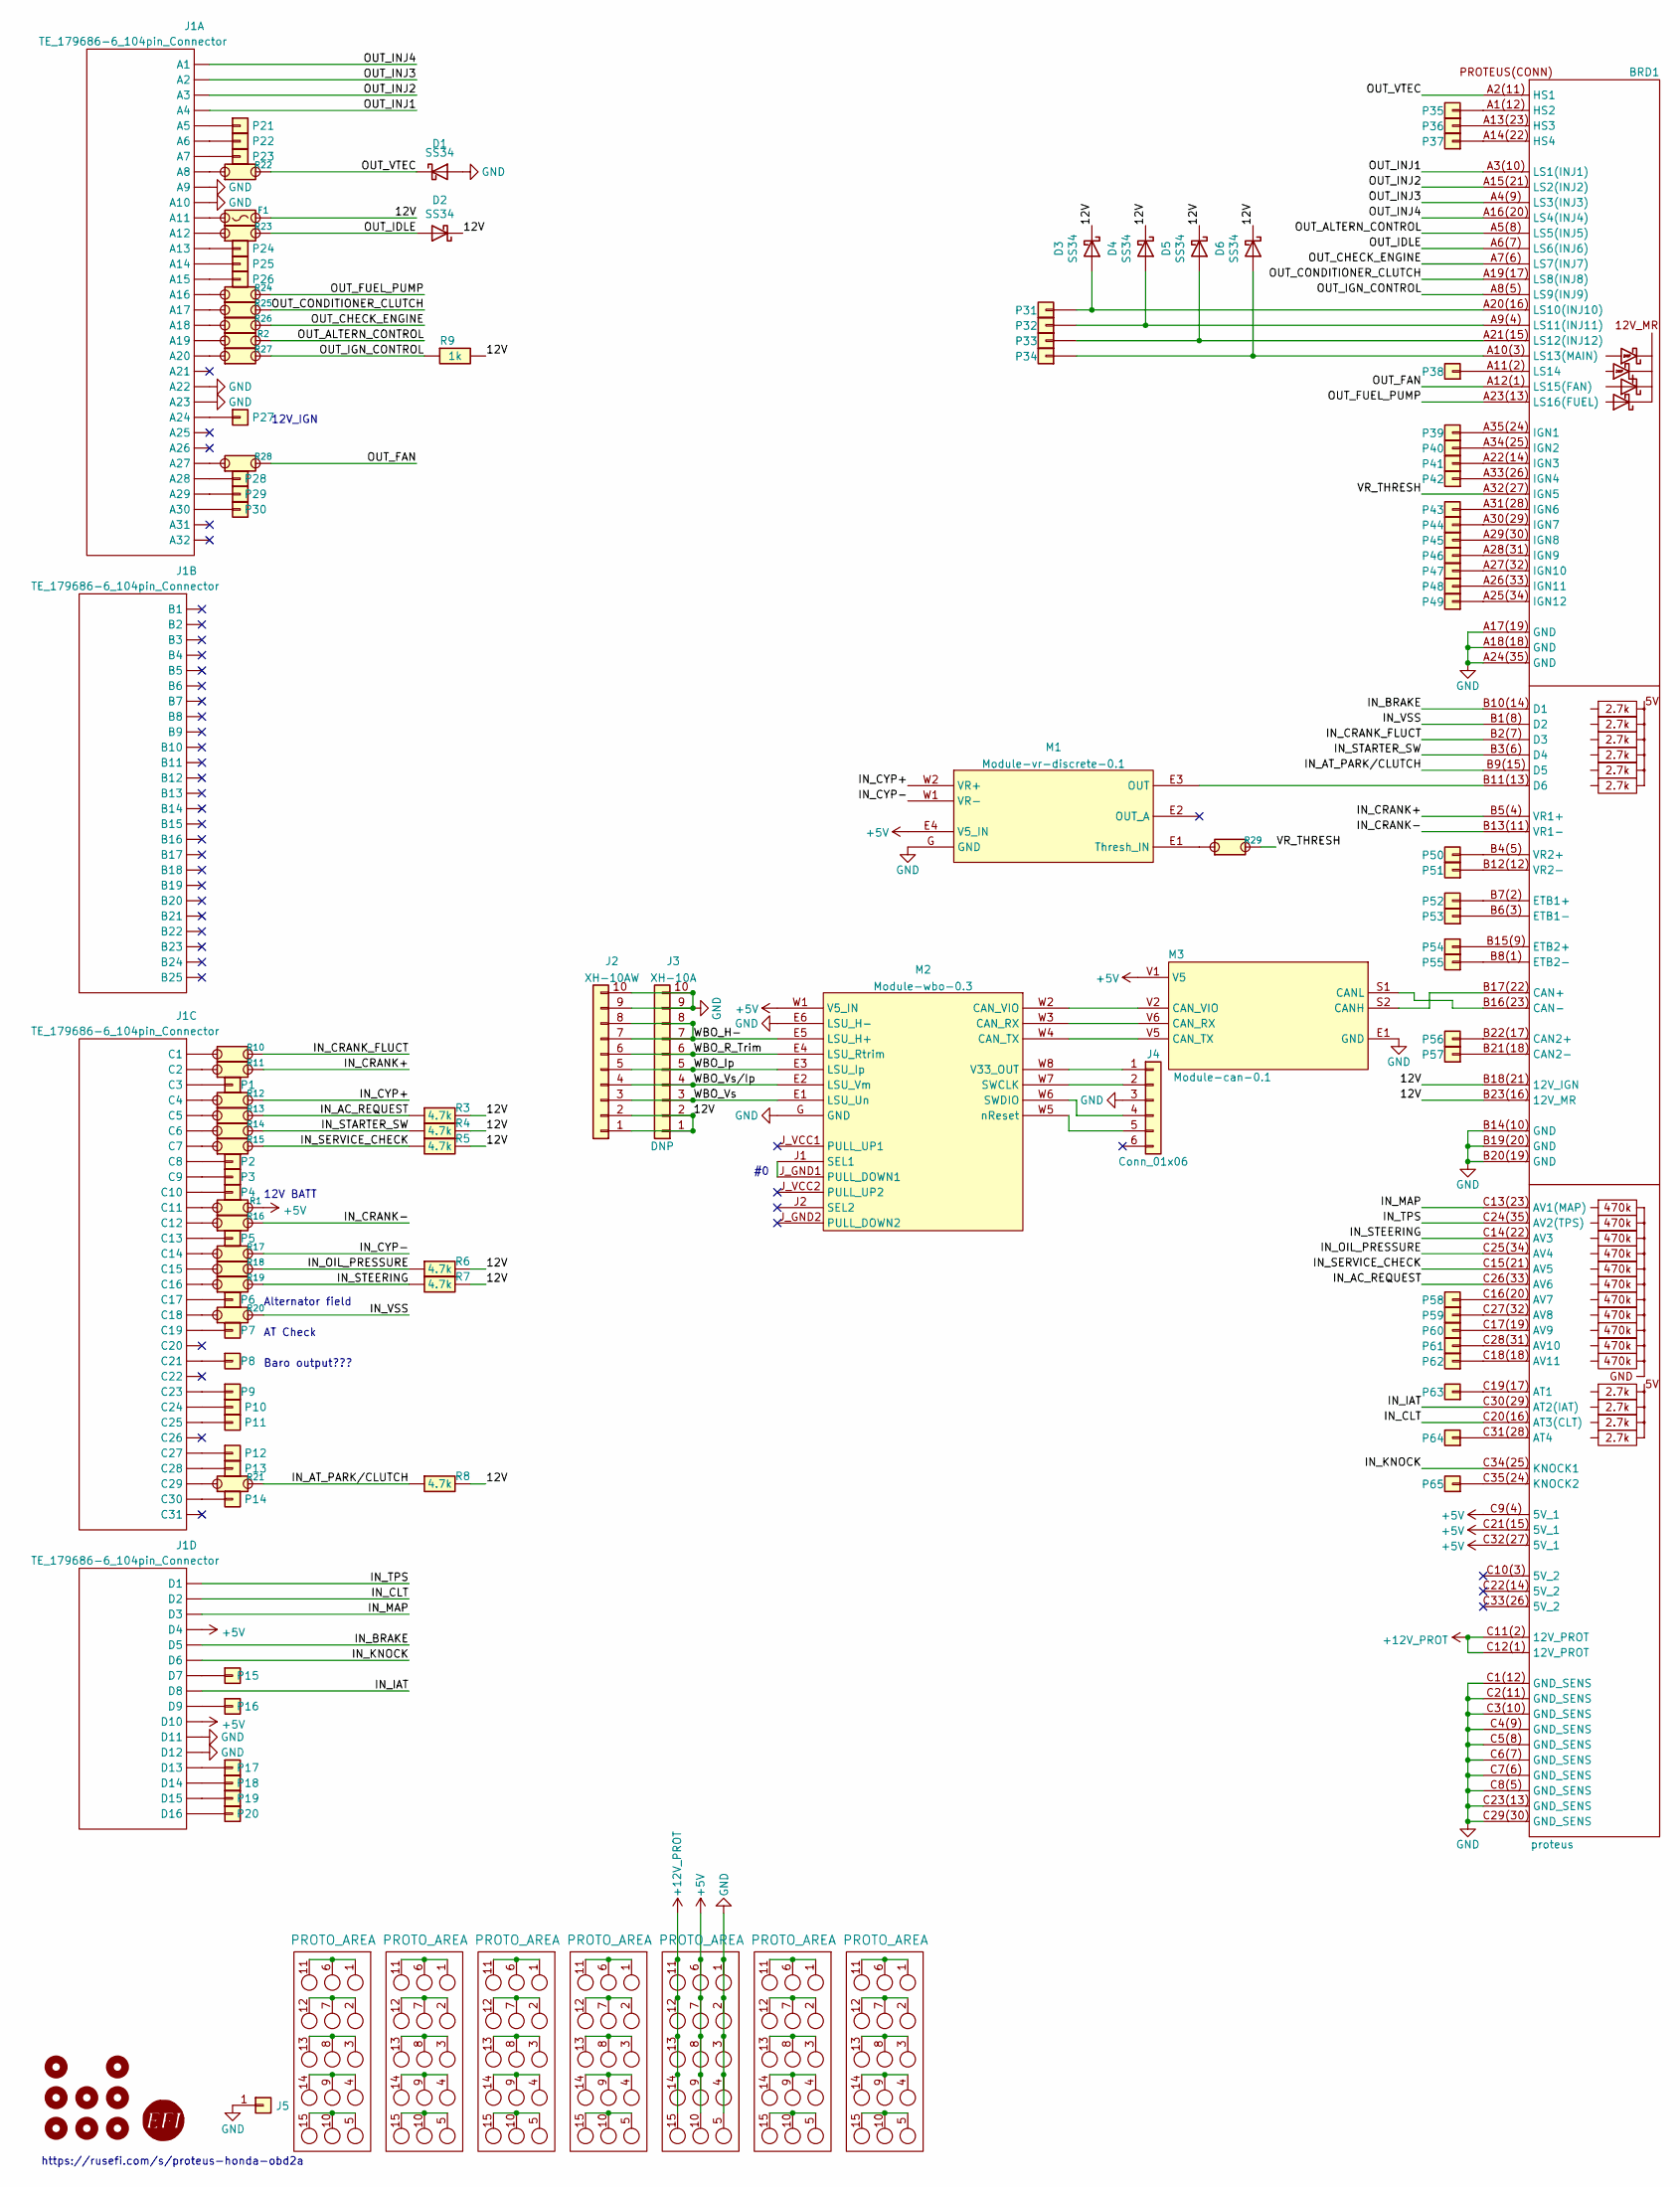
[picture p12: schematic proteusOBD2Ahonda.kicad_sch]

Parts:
BRD1: proteus
D1, D2, D3, D4, D5, D6: SS34; D_SMA; LCSC C8678
F1: Fuse-Pad-Pad; PAD-1206-PAD; LCSC C182446
G1: RUSEFI_LOGO; rusefi_logo
G2, G3, G4, G5, G6, G7, G8: PROTO_AREA
H1, H2, H3, H4, H5, H6, H7, H8: MountingHole; MountingHole_4.3mm_M4
J1: TE_179686-6_104pin_Connector
J2: XH-10AW; JST_XH_S10B-XH-A_1x10_P2.50mm_Horizontal; LCSC C14652
J3: XH-10A; JST_XH_B10B-XH-A_1x10_P2.50mm_Vertical; LCSC C8885
J4: Conn_01x06; PinHeader_1x06_P2.54mm_Vertical
J5: Conn_01x01; TestPoint_Pad_D2.0mm
M1: Module-vr-discrete-0.1; vr-discrete
M2: Module-wbo-0.3; wbo
M3: Module-can-0.1; can
P1, P2, P3, P4, P5, P6, P7, P8, P9, P10, P11, P12, P13, P14, P15, P16, P17, P18, P19, P20, P21, P22, P23, P24, P25, P26, P27, P28, P29, P30, P31, P32, P33, P34, P35, P36, P37, P38, P39, P40, P41, P42, P43, P44, P45, P46, P47, P48, P49, P50, P51, P52, P53, P54, P55, P56, P57, P58, P59, P60, P61, P62, P63, P64, P65: Pad; PAD-TH
R1, R2, R10, R11, R12, R13, R14, R15, R16, R17, R18, R19, R20, R21, R22, R23, R24, R25, R26, R27, R28, R29: Jumper-Pad-Pad; PAD-0805-PAD; LCSC C17477
R3, R4, R5, R6, R7, R8: 4.7k; R0603; LCSC C23162
R9: 1k; R1206; LCSC C4410

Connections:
+5V: BRD1.C9(4) (5V_1), BRD1.C21(15) (5V_1), BRD1.C32(27) (5V_1), G6.6, G6.7, G6.8, G6.9, G6.10, J1.D4, J1.D10, M1.E4 (V5_IN), M2.W1 (V5_IN), M3.V1 (V5), R1.2
+12V_PROT: BRD1.C11(2) (12V_PROT), BRD1.C12(1) (12V_PROT), G6.11, G6.12, G6.13, G6.14, G6.15
/12V: BRD1.B18(21) (12V_IGN), BRD1.B23(16) (12V_MR), D2.1 (K), D3.1 (K), D4.1 (K), D5.1 (K), D6.1 (K), F1.2, J2.1, J2.2, J3.1, J3.2, R3.2, R4.2, R5.2, R6.2, R7.2, R8.2, R9.2
/IN_AC_REQUEST: BRD1.C26(33) (AV6), R3.1, R13.2
/IN_AT_PARK/CLUTCH: BRD1.B9(15) (D5), R8.1, R21.2
/IN_BRAKE: BRD1.B10(14) (D1), J1.D5
/IN_CLT: BRD1.C20(16) (AT3(CLT)), J1.D2
/IN_CRANK+: BRD1.B5(4) (VR1+), R11.2
/IN_CRANK-: BRD1.B13(11) (VR1-), R16.2
/IN_CRANK_FLUCT: BRD1.B2(7) (D3), R10.2
/IN_CYP+: M1.W2 (VR+), R12.2
/IN_CYP-: M1.W1 (VR-), R17.2
/IN_IAT: BRD1.C30(29) (AT2(IAT)), J1.D8
/IN_KNOCK: BRD1.C34(25) (KNOCK1), J1.D6
/IN_MAP: BRD1.C13(23) (AV1(MAP)), J1.D3
/IN_OIL_PRESSURE: BRD1.C25(34) (AV4), R6.1, R18.2
/IN_SERVICE_CHECK: BRD1.C15(21) (AV5), R5.1, R15.2
/IN_STARTER_SW: BRD1.B3(6) (D4), R4.1, R14.2
/IN_STEERING: BRD1.C14(22) (AV3), R7.1, R19.2
/IN_TPS: BRD1.C24(35) (AV2(TPS)), J1.D1
/IN_VSS: BRD1.B1(8) (D2), R20.2
/OUT_ALTERN_CONTROL: BRD1.A5(8) (LS5(INJ5)), R2.2
/OUT_CHECK_ENGINE: BRD1.A7(6) (LS7(INJ7)), R26.2
/OUT_CONDITIONER_CLUTCH: BRD1.A19(17) (LS8(INJ8)), R25.2
/OUT_FAN: BRD1.A12(1) (LS15(FAN)), R28.2
/OUT_FUEL_PUMP: BRD1.A23(13) (LS16(FUEL)), R24.2
/OUT_IDLE: BRD1.A6(7) (LS6(INJ6)), D2.2 (A), R23.2
/OUT_IGN_CONTROL: BRD1.A8(5) (LS9(INJ9)), R9.1, R27.2
/OUT_INJ1: BRD1.A3(10) (LS1(INJ1)), J1.A4
/OUT_INJ2: BRD1.A15(21) (LS2(INJ2)), J1.A3
/OUT_INJ3: BRD1.A4(9) (LS3(INJ3)), J1.A2
/OUT_INJ4: BRD1.A16(20) (LS4(INJ4)), J1.A1
/OUT_VTEC: BRD1.A2(11) (HS1), D1.1 (K), R22.2
/VR_THRESH: BRD1.A32(27) (IGN5), R29.2
/WBO_H-: J2.7, J2.8, J3.7, J3.8, M2.E5 (LSU_H+)
/WBO_Ip: J2.5, J3.5, M2.E3 (LSU_Ip)
/WBO_R_Trim: J2.6, J3.6, M2.E4 (LSU_Rtrim)
/WBO_Vs: J2.3, J3.3, M2.E1 (LSU_Un)
/WBO_Vs/Ip: J2.4, J3.4, M2.E2 (LSU_Vm)
GND: BRD1.A17(19) (GND), BRD1.A18(18) (GND), BRD1.A24(35) (GND), BRD1.B14(10) (GND), BRD1.B19(20) (GND), BRD1.B20(19) (GND), BRD1.C1(12) (GND_SENS), BRD1.C2(11) (GND_SENS), BRD1.C3(10) (GND_SENS), BRD1.C4(9) (GND_SENS), BRD1.C5(8) (GND_SENS), BRD1.C6(7) (GND_SENS), BRD1.C7(6) (GND_SENS), BRD1.C8(5) (GND_SENS), BRD1.C23(13) (GND_SENS), BRD1.C29(30) (GND_SENS), D1.2 (A), G6.1, G6.2, G6.3, G6.4, G6.5, J1.A9, J1.A10, J1.A22, J1.A23, J1.D11, J1.D12, J2.9, J2.10, J3.9, J3.10, J4.3, J5.1, M1.G (GND), M2.E6 (LSU_H-), M2.G (GND), M3.E1 (GND)
unnamed: BRD1.A1(12) (HS2), P35.1
unnamed: BRD1.A9(4) (LS11(INJ11)), D4.2 (A), P32.1
unnamed: BRD1.A10(3) (LS13(MAIN)), D6.2 (A), P34.1
unnamed: BRD1.A11(2) (LS14), P38.1
unnamed: BRD1.A13(23) (HS3), P36.1
unnamed: BRD1.A14(22) (HS4), P37.1
unnamed: BRD1.A20(16) (LS10(INJ10)), D3.2 (A), P31.1
unnamed: BRD1.A21(15) (LS12(INJ12)), D5.2 (A), P33.1
unnamed: BRD1.A22(14) (IGN3), P41.1
unnamed: BRD1.A25(34) (IGN12), P49.1
unnamed: BRD1.A26(33) (IGN11), P48.1
unnamed: BRD1.A27(32) (IGN10), P47.1
unnamed: BRD1.A28(31) (IGN9), P46.1
unnamed: BRD1.A29(30) (IGN8), P45.1
unnamed: BRD1.A30(29) (IGN7), P44.1
unnamed: BRD1.A31(28) (IGN6), P43.1
unnamed: BRD1.A33(26) (IGN4), P42.1
unnamed: BRD1.A34(25) (IGN2), P40.1
unnamed: BRD1.A35(24) (IGN1), P39.1
unnamed: BRD1.B4(5) (VR2+), P50.1
unnamed: BRD1.B6(3) (ETB1-), P53.1
unnamed: BRD1.B7(2) (ETB1+), P52.1
unnamed: BRD1.B8(1) (ETB2-), P55.1
unnamed: BRD1.B11(13) (D6), M1.E3 (OUT)
unnamed: BRD1.B12(12) (VR2-), P51.1
unnamed: BRD1.B15(9) (ETB2+), P54.1
unnamed: BRD1.B16(23) (CAN-), M3.S1 (CANL)
unnamed: BRD1.B17(22) (CAN+), M3.S2 (CANH)
unnamed: BRD1.B21(18) (CAN2-), P57.1
unnamed: BRD1.B22(17) (CAN2+), P56.1
unnamed: BRD1.C16(20) (AV7), P58.1
unnamed: BRD1.C17(19) (AV9), P60.1
unnamed: BRD1.C18(18) (AV11), P62.1
unnamed: BRD1.C19(17) (AT1), P63.1
unnamed: BRD1.C27(32) (AV8), P59.1
unnamed: BRD1.C28(31) (AV10), P61.1
unnamed: BRD1.C31(28) (AT4), P64.1
unnamed: BRD1.C35(24) (KNOCK2), P65.1
unnamed: F1.1, J1.A11
unnamed: G2.1, G2.6, G2.11
unnamed: G2.5, G2.10, G2.15
unnamed: G2.2, G2.7, G2.12
unnamed: G2.3, G2.8, G2.13
unnamed: G2.4, G2.9, G2.14
unnamed: G3.1, G3.6, G3.11
unnamed: G3.5, G3.10, G3.15
unnamed: G3.2, G3.7, G3.12
unnamed: G3.3, G3.8, G3.13
unnamed: G3.4, G3.9, G3.14
unnamed: G4.1, G4.6, G4.11
unnamed: G4.5, G4.10, G4.15
unnamed: G4.2, G4.7, G4.12
unnamed: G4.3, G4.8, G4.13
unnamed: G4.4, G4.9, G4.14
unnamed: G5.1, G5.6, G5.11
unnamed: G5.5, G5.10, G5.15
unnamed: G5.2, G5.7, G5.12
unnamed: G5.3, G5.8, G5.13
unnamed: G5.4, G5.9, G5.14
unnamed: G7.1, G7.6, G7.11
unnamed: G7.5, G7.10, G7.15
unnamed: G7.2, G7.7, G7.12
unnamed: G7.3, G7.8, G7.13
unnamed: G7.4, G7.9, G7.14
unnamed: G8.1, G8.6, G8.11
unnamed: G8.5, G8.10, G8.15
unnamed: G8.2, G8.7, G8.12
unnamed: G8.3, G8.8, G8.13
unnamed: G8.4, G8.9, G8.14
unnamed: J1.A5, P21.1
unnamed: J1.A6, P22.1
unnamed: J1.A7, P23.1
unnamed: J1.A8, R22.1
unnamed: J1.A12, R23.1
unnamed: J1.A13, P24.1
unnamed: J1.A14, P25.1
unnamed: J1.A15, P26.1
unnamed: J1.A16, R24.1
unnamed: J1.A17, R25.1
unnamed: J1.A18, R26.1
unnamed: J1.A19, R2.1
unnamed: J1.A20, R27.1
unnamed: J1.A24, P27.1
unnamed: J1.A27, R28.1
unnamed: J1.A28, P28.1
unnamed: J1.A29, P29.1
unnamed: J1.A30, P30.1
unnamed: J1.C1, R10.1
unnamed: J1.C2, R11.1
unnamed: J1.C3, P1.1
unnamed: J1.C4, R12.1
unnamed: J1.C5, R13.1
unnamed: J1.C6, R14.1
unnamed: J1.C7, R15.1
unnamed: J1.C8, P2.1
unnamed: J1.C9, P3.1
unnamed: J1.C10, P4.1
unnamed: J1.C11, R1.1
unnamed: J1.C12, R16.1
unnamed: J1.C13, P5.1
unnamed: J1.C14, R17.1
unnamed: J1.C15, R18.1
unnamed: J1.C16, R19.1
unnamed: J1.C17, P6.1
unnamed: J1.C18, R20.1
unnamed: J1.C19, P7.1
unnamed: J1.C21, P8.1
unnamed: J1.C23, P9.1
unnamed: J1.C24, P10.1
unnamed: J1.C25, P11.1
unnamed: J1.C27, P12.1
unnamed: J1.C28, P13.1
unnamed: J1.C29, R21.1
unnamed: J1.C30, P14.1
unnamed: J1.D7, P15.1
unnamed: J1.D9, P16.1
unnamed: J1.D13, P17.1
unnamed: J1.D14, P18.1
unnamed: J1.D15, P19.1
unnamed: J1.D16, P20.1
unnamed: J4.1, M2.W8 (V33_OUT)
unnamed: J4.2, M2.W7 (SWCLK)
unnamed: J4.4, M2.W6 (SWDIO)
unnamed: J4.5, M2.W5 (nReset)
unnamed: M1.E1 (Thresh_IN), R29.1
unnamed: M2.J1 (SEL1), M2.J_GND1 (PULL_DOWN1)
unnamed: M2.W2 (CAN_VIO), M3.V2 (CAN_VIO)
unnamed: M2.W3 (CAN_RX), M3.V6 (CAN_RX)
unnamed: M2.W4 (CAN_TX), M3.V5 (CAN_TX)

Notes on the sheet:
Alternator field
Baro output???
12V_IGN
https://rusefi.com/s/proteus-honda-obd2a
12V BATT
AT Check

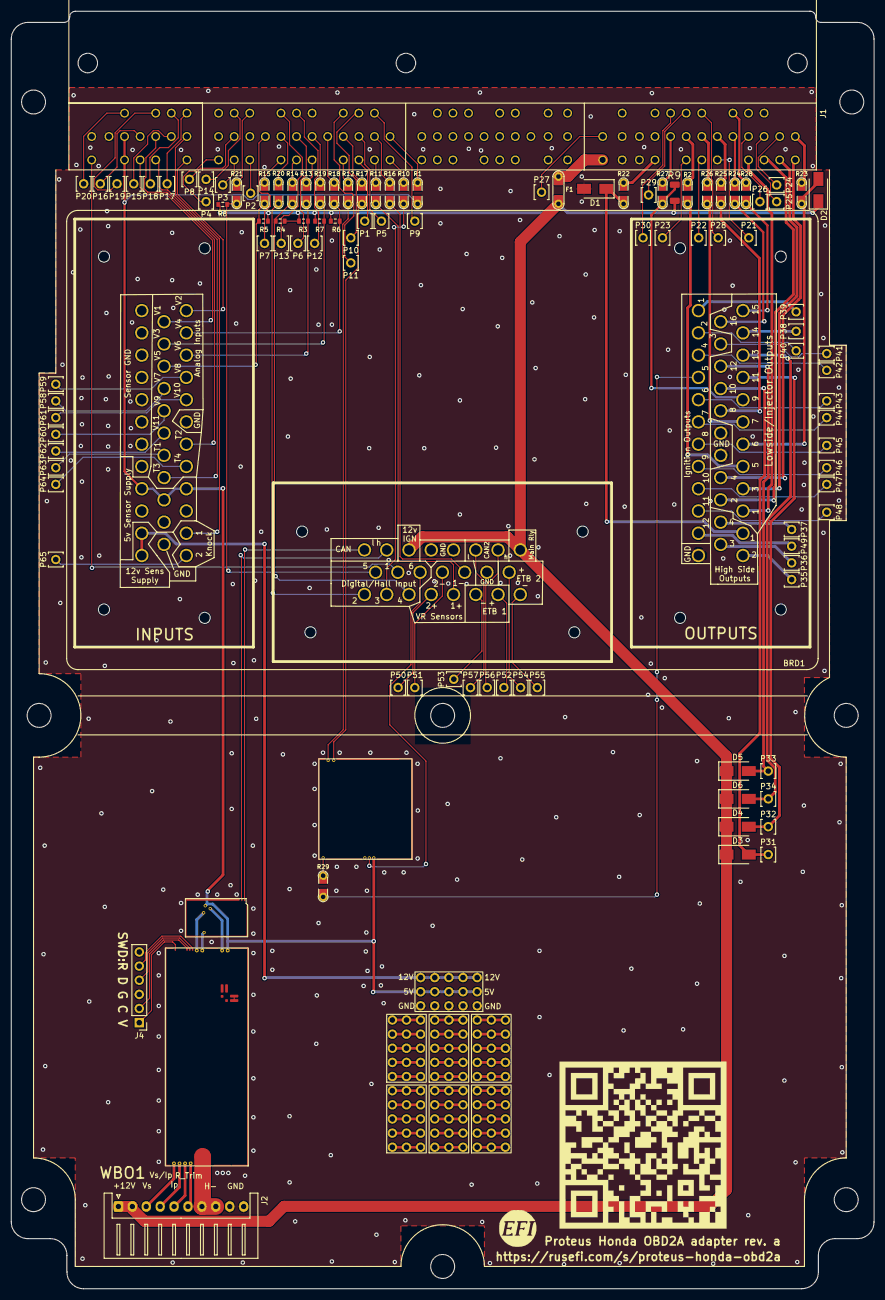
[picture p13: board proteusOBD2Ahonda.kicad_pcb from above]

Board: 2 copper layers, 155.0 x 229.5 mm, 125 parts (1 on the bottom side), 169 nets.

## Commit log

2021-09-29 104 kicad component
2021-10-01 Connector and proteus
    [proteusOBD2Ahonda.kicad_sch]
2021-10-27 Upd pinout
    [proteusOBD2Ahonda.kicad_pcb, proteusOBD2Ahonda.kicad_sch]
2021-10-30 Upd sch, pcb
    [proteusOBD2Ahonda.kicad_pcb, proteusOBD2Ahonda.kicad_sch]
2021-10-31 Upd pcb
    [proteusOBD2Ahonda.kicad_pcb, proteusOBD2Ahonda.kicad_sch]
2021-11-04 Fab preview
    [OBD2Ahonda-BOM.csv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]
2024-01-12 [skip actions] Auto-generated board v2.1
    [proteusOBD2Ahonda-B_Cu.gbl, proteusOBD2Ahonda-B_Mask.gbs, proteusOBD2Ahonda-B_Paste.gbp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]
2024-01-12 2024 process
    [bom_replace_proteusOBD2Ahonda-test.csv]
2024-01-12 just mimicking 2024 convention
    [OBD2Ahonda-BOM.csv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]
